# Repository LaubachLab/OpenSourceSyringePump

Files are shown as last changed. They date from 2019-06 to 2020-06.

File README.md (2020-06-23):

# Open Source Syringe Pump

### Updated Publication based on this project: (Amarante et al., 2019) https://www.eneuro.org/content/eneuro/6/5/ENEURO.0240-19.2019.full.pdf

*Developed by Linda Amarante, Jonathan Newport, Megan Mitchell, Joshua Wilson, and Mark Laubach in the Center for Behavioral Neuroscience, Departments of Biology and Physics, and Design and Build Lab at American University.*

The neural basis of reward processing is a major topic in neuroscience. Many studies examine reward coding by varying the amount of fluid given to experimental animals as they perform a behavioral task. Most devices used in these studies are not capable of delivering different volumes over a common period of time. As such, reward coding is confounded by temporal information. To resolve this issue, we developed a syringe pump controller that is capable of delivering different fluid volumes, in the range used in behavioral studies, over common periods of time. Here, we report the designs of all components of the pump and the protocols needed to create and use it.

There are two parts of this project:

1. Syringe Holder: To house the syringe, we modified a 3D printed syringe pump design ([Wijnen et al., 2014](https://journals.plos.org/plosone/article?id=10.1371/journal.pone.0107216)) and some modifications described [HERE](https://www.appropedia.org/Lynch_open_source_syringe_pump_modifications). This part is not essential for the project, as any syringe holder that can fit a 60 mL syringe will do. We made additional modifications to accommodate a NEMA-17 integrated stepper motor, and for the pump holder to fit either a 30 or 60 mL syringe. We also adjusted the end pieces to have a more stable base for the holder. stl files for the 3D printed parts for a 60 mL syringe are available in this repository.
2. Control Board: The main innovation of the project is the syringe pump controller and programming library. The schematic, printed circuit board (PCB), and manufacturing files are available in this repository. PCBs were designed using AutoCAD Eagle (Autodesk) software. Boards are also available directly from various PCB manufacturing houses, including OSH Park: [Open Source Syringe Pump PCB](https://oshpark.com/shared_projects/VtseE2Ia))

The Bill of Materials for this device are provided in [OpenSourceSyringePumpBOM.xlsx](https://github.com/LaubachLab/OpenSourceSyringePump/blob/master/OpenSourceSyringePumpBOM.xlsx).

Build instructions are provided in provided in [OpenSourceSyringePumpBuildInstructions.pdf](https://github.com/LaubachLab/OpenSourceSyringePump/blob/master/OpenSourceSyringePumpBuildInstructions.pdf).

The mathematical basis for how the device works to deliver dissimilar volumes of fluid in equal time intervals is described in [t_min and velocity formulas.pdf](https://github.com/LaubachLab/OpenSourceSyringePump/blob/master/t_min%20and%20velocity%20formulas.pdf).

Images of the control board and [teensy](https://www.pjrc.com/teensy/) controller are provided below:

Syringe Board Pinout

Teensy Pinout

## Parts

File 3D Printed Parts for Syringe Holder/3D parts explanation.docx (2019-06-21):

Part Name | Description
30cc syringe body holder.stl | Two of these snap into the smooth rods and hold the smaller 30 mL syringe body in place at the front of the pump
30cc syringe plunger holder.stl | Two pieces; used to hold the plunger of the syringe in place against the carriage
60cc syringe body holder.stl | Snaps into the smooth metal rods and holds the larger 60 mL syringe body in place at the front of the pump
60cc syringe plunger holder bottom.stl | This piece is screwed onto the carriage and creates a cavity for the syringe plunger to fit into
60cc syringe plunger holder top.stl | Holds the syringe plunger in place against the carriage
Escape mechanism blade.stl | If the escape mechanism modification is being used, this piece replaces the function of the nut in the carriage and can be secured with a rubber band and then easily removed to move the carriage piece backwards
Carriage with escape mod.stl | The crucial piece that pushes the syringe plunger forwards as it advances on the metal rods when the motor is activated
Front end base.stl | This is a modified front end that has a wider base added for stability
Front end.stl | Front end of the pump where the metal rods are secured
Motor end.stl | Back end of the pump where the central metal rod is connected to the motor via a coupler and the side rods are secured.
Motor holder base.stl | Motor end; modified to cover the NEMA17 motor and has a wider base for stability

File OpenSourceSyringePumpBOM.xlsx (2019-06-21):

Open Source Syringe Pump - Controller – Bill of Materials
Item | Manufacturer | Part | Supplier | Supplier Part # | Alternative Part # | Qty. | Price | Notes
NEMA 17 Stepper Motor (standalone) | Applied Motion Products | STM17R-3NN (https://www.applied-motion.com/products/integrated-steppers/stm17r-3nn) | Applied Motion Products or Walker | Walker (https://www.walkerindustrial.com/STM17R-3NN-Applied-Motion-Products-p/STM17R-3NN.htm?gsn) |  | 1 | $118.00
15Vdc 36W 2.1mm Power Supply | CUI | SDI36-15-U-P5 | Mouser | 490-SDI36-15-U-P5 (https://www.mouser.com/ProductDetail/CUI/SDI36-15-U-P5) |  | 1 | $16.39
Printed Circuit Board | OSH Park | OpenSourceSyringePump-v01 | OSH Park | https://oshpark.com/shared_projects/VtseE2Ia |  | 1 | $29.95
2.1mm Power Jack | CUI | PJ-079AH | Mouser | 490-PJ-079AH (https://www.mouser.com/ProductDetail/490-PJ-079AH) |  | 1 | $1.36 | 24Vdc Max Rated
P-Channel MOSFET | ON Semiconductor | FQP47P06 | Mouser | 512-FQP47P06 (https://www.mouser.com/ProductDetail/ON-Semiconductor-Fairchild/FQP47P06) |  | 1 | $2.68 | Reverse Polarity Protection, high Vgs tolerance, low Rds-on, low Vgs-thresh
100kΩ Resistor | Yageo | CFR-25JR-52-100K | Mouser | 603-CFR-25JR-52100K (https://www.mouser.com/ProductDetail/Yageo/CFR-25JR-52-100K) |  | 1 | $0.10 | any 100k resistor should work
10V Zener Diode | ON Semiconductor | BZX79C10 | Mouser | 512-BZX79C10 |  | 1 | $0.13 | any 10V zener should work
Isolated DC/DC Converter | Murata | NCS1S2405SC | Mouser | 580-NCS1S2405SC (https://www.mouser.com/ProductDetail/580-NCS1S2405SC) |  | 1 | $8.46 | 9-36V input 24V nominal DC-DC converter
PTC Resettable Polyfuse | Bourns | MF-R025 | Mouser | 652-MFR025 (https://www.mouser.com/ProductDetail/Bourns/MF-R025) |  | 1 | $0.60 | 250mA Hold, 500mA trip, provides protection to microcontroller and 5V circuitry
2AG Fuse Holder | Littlefuse | 02540101Z | Mouser | 576-02540101Z (https://www.mouser.com/ProductDetail/576-02540101Z) |  | 1 | $1.21 | 2AG Fuse holder, protection for motor
2AG fast-blow 2A fuse | Littlefuse | 0208002.MXP | Mouser | 576-0208002.MXP (https://www.mouser.com/ProductDetail/576-0208002.MXP) |  | 10 | $4.09 | buy extra fuses!
1uF 50V Ceramic Capacitor | Vishay | K105Z20Y5VF5TL2 | Mouser | 594-K105Z20Y5VF5TL2 (https://www.mouser.com/ProductDetail/Vishay-BC-Components/K105Z20Y5VF5TL2) |  | 2 | $0.65
10uF 25V Tantalum Capacitor | AVX | TAP106K025SCS | Mouser | 581-TAP106K025SCS (https://www.mouser.com/ProductDetail/AVX/TAP106K025SCS) |  | 1 | $0.90
100uF 63V Low ESR Electrolytic Capacitor | Panasonic | EEUFR1H101 | Mouser | 667-EEU-FR1J101 (https://www.mouser.com/ProductDetail/667-EEU-FR1J101) |  | 1 | $0.62
Teensy 3.2 | PJRC.com | Teensy 3.2 | Sparkfun | 13736 |  | 1 | $19.95
TeensyView | Sparkfun | TeensyView | Sparkfun | 14048 |  | 1 | $15.95
Long Headers | Sparkfun | PRT-12693 | Sparkfun | 12693 |  | 2 | $0.75 | 0.1" Male Headers for Teensy and TeensyView Connections
Female Headers | Sparkfun | PRT-00115 | Sparkfun | 115 |  | 2 | $1.50 | 0.1" Female Headers for socketing Teensy and/or Teensyview
24 Detent Encoder w/Switch | Bourns | PEC11R-4220F-S0024 | Mouser | 652-PEC11R-4220F-S24 (https://www.mouser.com/ProductDetail/Bourns/PEC11R-4220F-S0024) |  | 1 | $1.63
Plastic Knob for D-Shaft Encoder | Eagle Plastic Devices | 450-BA600 | Mouser | 450-BA600 (https://www.mouser.com/ProductDetail/Eagle-Plastic-Devices/450-BA600) |  | 1 | $1.29 | Plain, could spice up with colors
Small Switches | ALPS | SKRGAFD010 | Mouser | 688-SKRGAFD010 (https://www.mouser.com/ProductDetail/ALPS/SKRGAFD010) |  | 3 | $0.18
Limit Switches | Omron | D2F-L-D3 | Mouser | 653-D2F-L-D3 (https://www.mouser.com/ProductDetail/653-D2F-L-D3) |  | 2 | $1.86
Indicator LED | Kingbright | WP710A10GD5V | Mouser | 604-WP710A10GD5V (https://www.mouser.com/ProductDetail/Kingbright/WP710A10GD5V) |  | 1 | $0.64
Screw Terminal Connectors for Motor | TE Connectivity | 282834-6 | Mouser | 571-282834-6 (https://www.mouser.com/ProductDetail/571-282834-6) | Pololu 2495 (https://www.pololu.com/product/2495) | 1 | $4.72
Screw Terminal Connectors for I/O (optional) | TE Connectivity | 1-282834-0 | Mouser | 571-1-282834-0 (https://www.mouser.com/ProductDetail/571-1-282834-0) | Pololu 2499 (https://www.pololu.com/product/2499) | 1 | $7.06
Limit Switch Connectors (optional) | TE Connectivity | 282834-3 | Mouser | 571-2828343 (https://www.mouser.com/ProductDetail/571-2828343) | Pololu 2492 (https://www.pololu.com/product/2492) | 1 | $1.11
 |  |  |  |  |  | Total: | $241.78

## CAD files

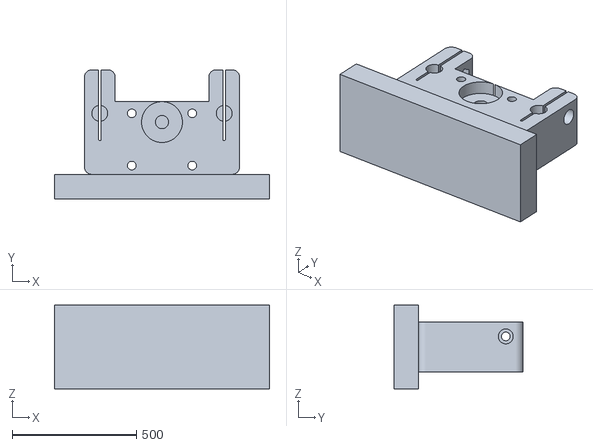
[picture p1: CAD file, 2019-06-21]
3D Printed Parts for Syringe Holder/front end base.stl
864.0 x 520.0 x 336.0

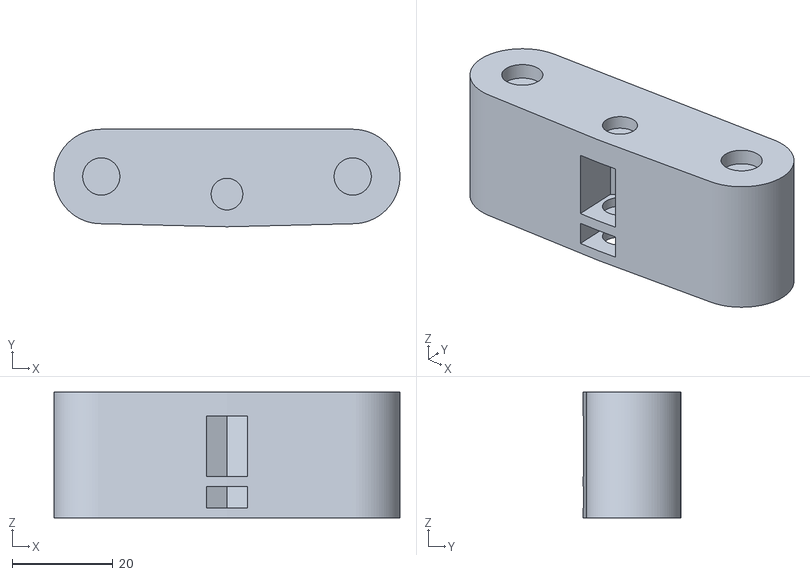
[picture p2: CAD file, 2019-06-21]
3D Printed Parts for Syringe Holder/Pearce MOST Syringe and Lynch Modified STLs/linear_actuator_v0-3.stl
68.8 x 19.4 x 25.0

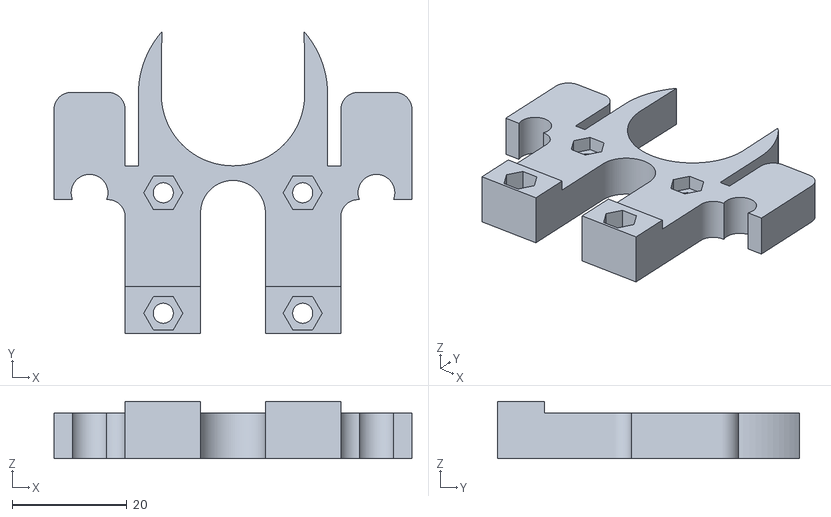
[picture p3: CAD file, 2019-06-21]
3D Printed Parts for Syringe Holder/30cc syringe body holder.stl
62.4 x 52.6 x 10.0

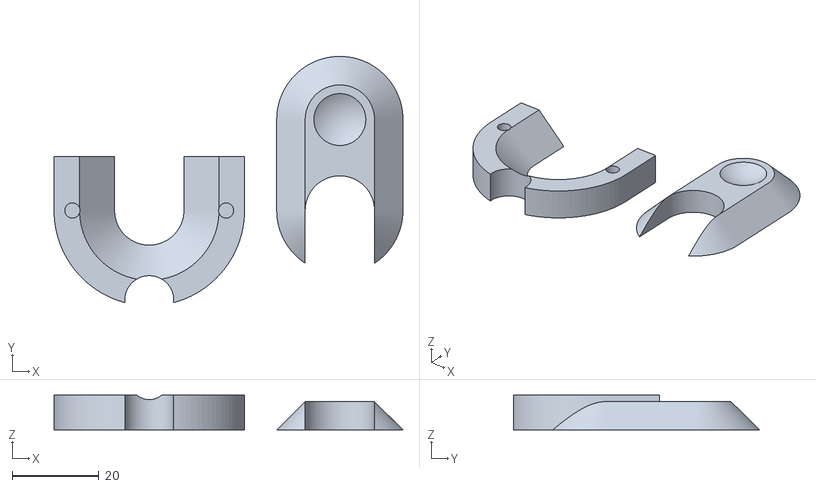
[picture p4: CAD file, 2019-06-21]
3D Printed Parts for Syringe Holder/30cc syringe plunger holder.stl
80.6 x 56.8 x 8.00

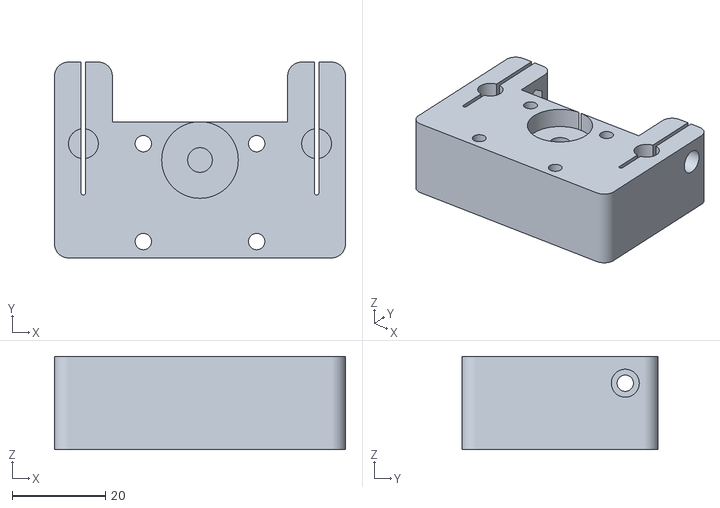
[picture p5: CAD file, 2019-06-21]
3D Printed Parts for Syringe Holder/Pearce MOST Syringe and Lynch Modified STLs/linear_actuator_v0-2.stl
62.4 x 42.0 x 20.0

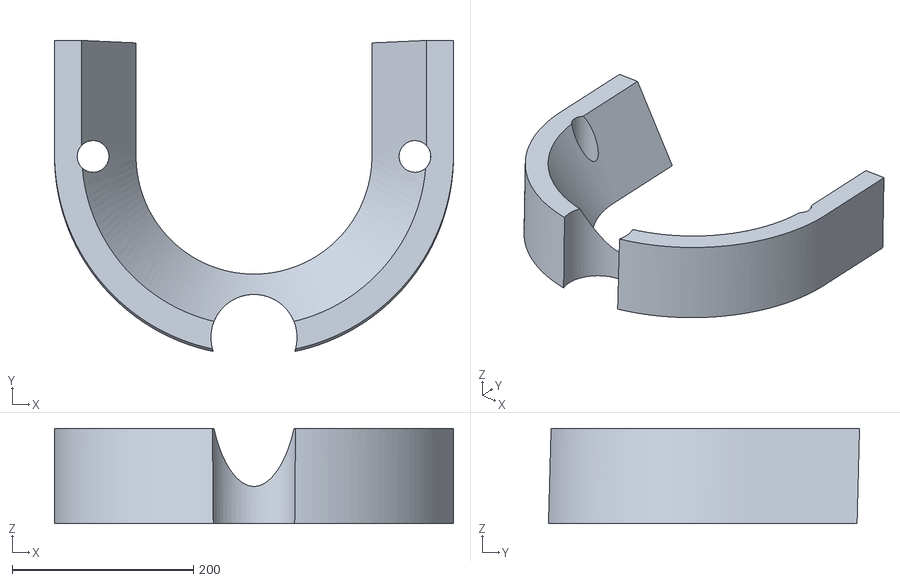
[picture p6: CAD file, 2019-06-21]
3D Printed Parts for Syringe Holder/60cc syringe plunger holder bottom.stl
440.0 x 343.1 x 105.0

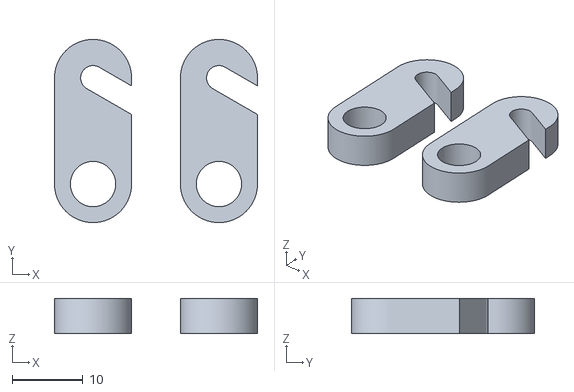
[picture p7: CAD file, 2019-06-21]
3D Printed Parts for Syringe Holder/Pearce MOST Syringe and Lynch Modified STLs/linear_actuator_v0-6.stl
28.7 x 25.9 x 5.00

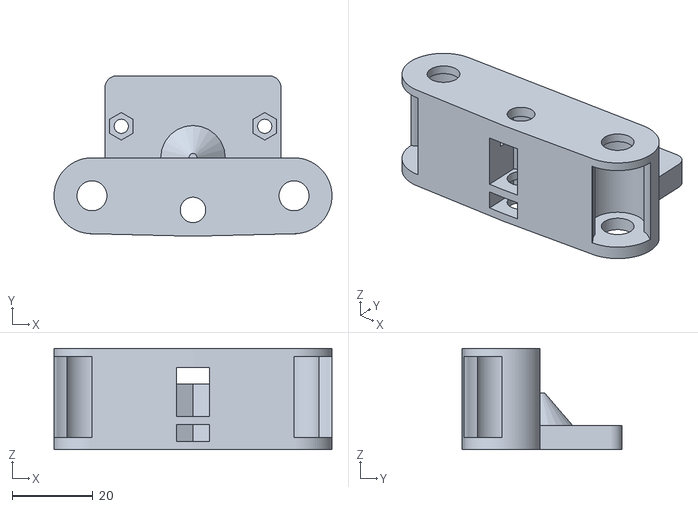
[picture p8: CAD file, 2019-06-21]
3D Printed Parts for Syringe Holder/carriage with escape mod.stl
68.8 x 39.7 x 25.0

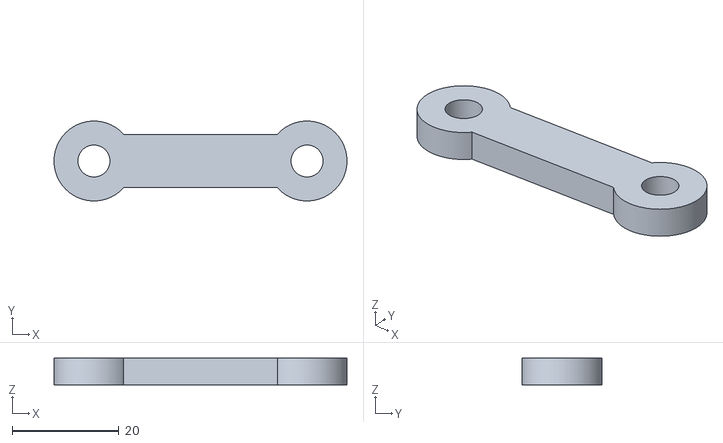
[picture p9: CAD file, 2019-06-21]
3D Printed Parts for Syringe Holder/Pearce MOST Syringe and Lynch Modified STLs/linear_actuator_v0-8.stl
55.0 x 15.0 x 5.00

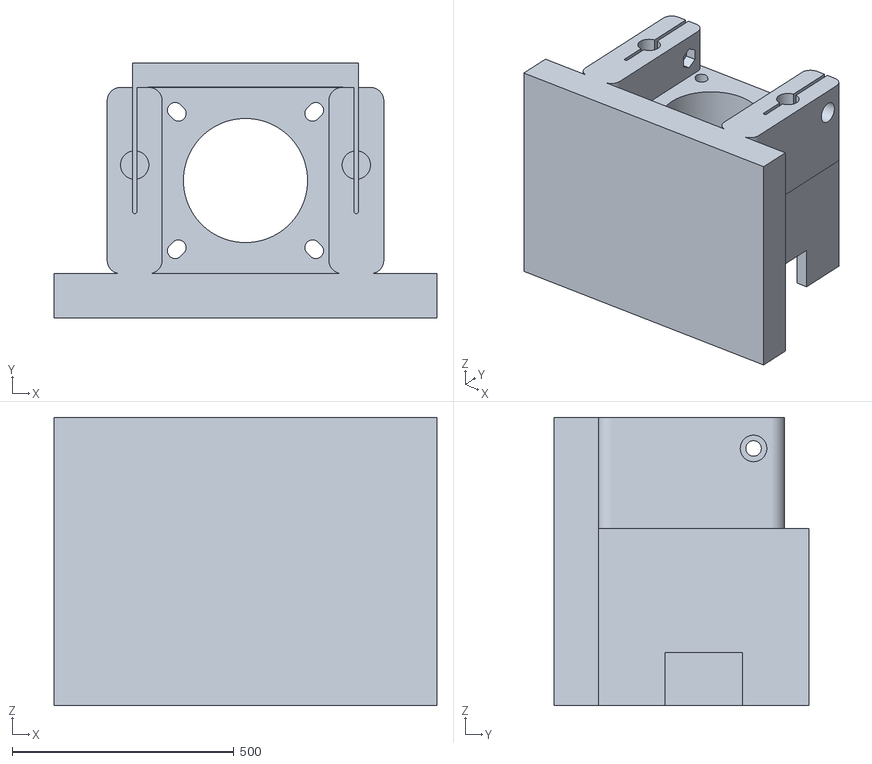
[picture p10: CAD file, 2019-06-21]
3D Printed Parts for Syringe Holder/motor holder base.stl
864.0 x 575.0 x 650.0

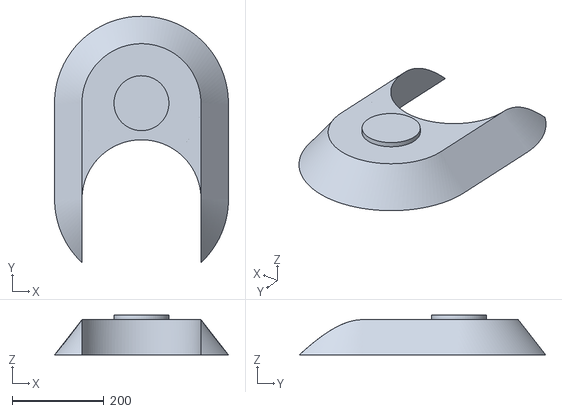
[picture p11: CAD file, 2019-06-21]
3D Printed Parts for Syringe Holder/60cc syringe plunger holder top.stl
380.2 x 538.7 x 87.0

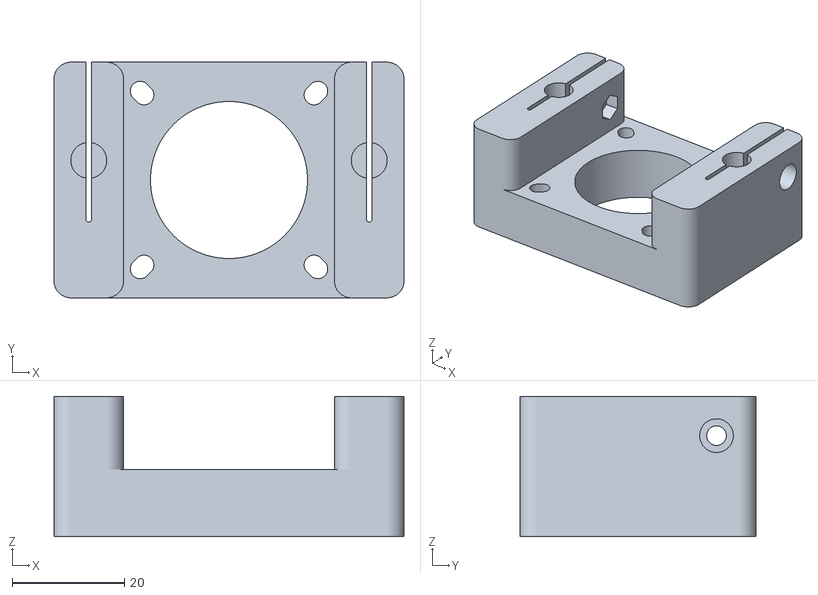
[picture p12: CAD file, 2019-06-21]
3D Printed Parts for Syringe Holder/Pearce MOST Syringe and Lynch Modified STLs/linear_actuator_v0-1.stl
62.4 x 42.0 x 25.0

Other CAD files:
3D Printed Parts for Syringe Holder/Pearce MOST Syringe and Lynch Modified STLs/linear_actuator_v0-4.stl
3D Printed Parts for Syringe Holder/60cc syringe body holder.stl
3D Printed Parts for Syringe Holder/blade.stl
